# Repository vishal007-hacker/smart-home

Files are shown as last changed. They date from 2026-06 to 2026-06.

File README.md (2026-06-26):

# Smart Home 4-Channel AC Relay Controller

**WisRight Technologies Private Limited**

ESP32-based smart home controller for switching 4 independent 230V AC loads, with per-channel current and voltage sensing, manual override buttons, status LEDs, and an I²C LCD display.

The project is a complete KiCad 9 design — schematic, PCB layout, BOM, custom symbol/footprint for the HLK-PM01 AC-DC module, custom DRC rules for mains clearance, and Python generator scripts that build everything from a single `bom.csv`.

## Features

- **4 independent AC channels**, each with its own L/N/PE input terminal, fuse, relay, and L/N output terminal
- **Mains isolation** — HLK-PM01 isolated AC-DC module (230VAC → 5VDC, 600mA, 2.1 kV isolation)
- **Per-channel current sensing** — ACS712-05B Hall-effect IC (±5A, isolated)
- **Per-channel voltage sensing** — external ZMPT101B modules via I²C ADS1115 (16-bit, 4 channels)
- **Manual override** — 4 tactile buttons for local on/off control per channel
- **Status indication** — 4 green LEDs (one per channel) + 1 red power LED
- **I²C LCD support** — 4-pin header for an external 16×2 PCF8574 backpack LCD
- **UART programming header** — standard 6-pin pinout for any USB-to-serial adapter
- **Custom DRC rules** — 4mm HV-to-LV clearance, 3mm HV-to-HV, 2mm HV trace minimum, edge clearance
- **HV/LV isolation slot** — physical cut in the PCB between mains and logic sections

## Hardware overview

| Section | Parts |
|---|---|
| AC inputs | 4× Phoenix MKDS-1.5 3-pos terminals (L, N, PE per channel) |
| Protection | 4× T4A 5×20mm fuses (one per channel) + 1× S07K275 MOV across L1/N1 |
| Power supply | HLK-PM01 (230VAC → 5VDC) + AMS1117-3.3 (5V → 3.3V LDO) |
| Switching | 4× SANYOU SRD-05VDC SPDT relays (10A) driven by ULN2003A Darlington array |
| MCU | ESP32-WROOM-32E module (WiFi + Bluetooth) |
| AC outputs | 4× Phoenix MKDS-1.5 2-pos terminals (L_switched, N_passthrough per channel) |
| Current sense | 4× ACS712-05B (SOIC-8, ±5A range, internal isolation) |
| Voltage sense | 4× external ZMPT101B modules via 1× ADS1115 (I²C ADC at 0x48) |
| User interface | 4× 6mm tactile buttons + 4× green status LEDs + 1× red power LED + 4-pin I²C LCD header |
| Programming | 6-pin UART header (GND, +3V3, TXD0, RXD0, EN, IO0) |

Full bill of materials in [`bom.csv`](bom.csv) — 43 grouped rows, 76 component instances.

## Detailed components list

### Active devices

| Ref | Qty | Part | Package | Description |
|---|---|---|---|---|
| **U1** | 1 | ESP32-WROOM-32E | Module 18×25.5mm | Espressif WiFi+BT MCU, 240MHz dual-core, 4MB flash, integrated PCB antenna |
| **U2** | 1 | ULN2003A | DIP-16 | Texas Instruments 7-channel Darlington array (500mA per channel, up to 50V), drives relay coils |
| **U3** | 1 | AMS1117-3.3 | SOT-223-3 | Advanced Monolithic Systems 3.3V LDO regulator, 1A capacity, drops 5V→3.3V for ESP32 |
| **PS1** | 1 | HLK-PM01 | THT 34.2×20.2mm | Hi-Link AC-DC isolated SMPS module, 230VAC→5VDC @ 600mA, 2.1 kV isolation, 3W |
| **U4-U7** | 4 | ACS712ELCTR-05B | SOIC-8 | Allegro Hall-effect current sensor, ±5A range, 185 mV/A sensitivity, 2.1 kVrms isolation between IP± and signal pins |
| **U8** | 1 | ADS1115IDGSR | TSSOP-10 | Texas Instruments 16-bit Σ-Δ ADC, 4 single-ended channels, I²C interface, 860 SPS, PGA ±0.256V to ±6.144V (default address 0x48 with ADDR=GND) |
| **K1-K4** | 4 | SRD-05VDC-SL-C | THT | Sanyou SPDT relay, 5V coil ~70mA, contacts rated 10A @ 250VAC / 30VDC |

### Discrete components

| Ref | Qty | Value | Package | Use |
|---|---|---|---|---|
| **R1-R4** | 4 | 1 kΩ | 0805 SMD | Status LED current limit (D1-D4) |
| **R9** | 1 | 1 kΩ | 0805 SMD | Power LED current limit (D5) |
| **R5-R8** | 4 | 10 kΩ | 0805 SMD | Manual button pull-ups to +3V3 (SW1-SW4) |
| **R11** | 1 | 10 kΩ | 0805 SMD | ESP32 EN pin pull-up to +3V3 |
| **R12** | 1 | 10 kΩ | 0805 SMD | ESP32 BOOT (GPIO0) pull-up to +3V3 |
| **R13** | 1 | 4.7 kΩ | 0805 SMD | I²C SDA pull-up to +3V3 |
| **R14** | 1 | 4.7 kΩ | 0805 SMD | I²C SCL pull-up to +3V3 |
| **R15-R18** | 4 | 10 kΩ | 0805 SMD | ACS712 output divider (top) — scales 0-5V to 0-3.21V for ESP32 ADC |
| **R19-R22** | 4 | 18 kΩ | 0805 SMD | ACS712 output divider (bottom) |
| **C1** | 1 | 100 µF / 16V | Radial THT 6.3mm | HLK-PM01 +5V output bulk capacitor (absorbs ESP32 WiFi transient bursts) |
| **C2** | 1 | 10 µF | 0805 SMD | AMS1117 input cap |
| **C3** | 1 | 22 µF | 0805 SMD | AMS1117 output cap (recommended ≥22µF tantalum/ceramic for AMS1117 stability) |
| **C4** | 1 | 10 µF | 0805 SMD | ESP32 +3V3 bulk |
| **C5** | 1 | 100 nF | 0805 SMD | ESP32 3V3 decoupling (place within 3mm of module pin 2) |
| **C6** | 1 | 1 µF | 0805 SMD | EN pin RC delay (forms ~10ms power-up delay with R11=10k) |
| **C7** | 1 | 100 nF | 0805 SMD | ULN2003A VCC decoupling |
| **C8-C11** | 4 | 100 nF | 0805 SMD | ACS712 VCC decoupling (one per ACS712) |
| **C16** | 1 | 100 nF | 0805 SMD | ADS1115 VDD decoupling |
| **D1-D4** | 4 | LED 3mm green | THT | Per-channel relay status indicator |
| **D5** | 1 | LED 3mm red | THT | Power-on indicator (always on while +5V present) |
| **F1-F4** | 4 | T4A 5×20 mm | THT Schurter 0031.8201 holder | Slow-blow mains fuse, one per AC input channel |
| **RV1** | 1 | S07K275 | Disc D9mm | EPCOS metal oxide varistor, 275 VAC clamping, surge protection across L1/N1 |

### Switches

| Ref | Qty | Type | Use |
|---|---|---|---|
| **SW1-SW4** | 4 | 6mm tactile THT | Manual override buttons (one per channel) — momentary press toggles the relay |
| **SW5** | 1 | 6mm tactile THT | BOOT button — hold during reset to enter ESP32 download mode |
| **SW6** | 1 | 6mm tactile THT | RESET button — pulls ESP32 EN low |

### Connectors

| Ref | Qty | Type | Use |
|---|---|---|---|
| **J1A, J1B, J1C, J1D** | 4 | Phoenix MKDS-1.5 3-pos screw terminal, 5.08mm pitch | AC input per channel: L (Live), N (Neutral), PE (Protective Earth) |
| **J2A, J2B, J2C, J2D** | 4 | Phoenix MKDS-1.5 2-pos screw terminal, 5.08mm pitch | AC switched output per channel: L_out, N_passthrough |
| **J3** | 1 | 1×6 pin header, 2.54mm pitch | UART programming: GND, +3V3, TXD0, RXD0, EN, IO0 |
| **J4** | 1 | 1×4 pin header, 2.54mm pitch | External 16×2 LCD via PCF8574 I²C backpack: GND, +5V, SDA, SCL |
| **J5, J6, J7, J8** | 4 | 1×3 pin header, 2.54mm pitch | External ZMPT101B voltage sensor per channel: GND, +3V3, VOUT |

### External modules (not on PCB — user-supplied)

| Module | Quantity | Purpose | Connection |
|---|---|---|---|
| 16×2 LCD with PCF8574 I²C backpack | 1 | Display | 4-wire to J4 (I²C address typically 0x27 or 0x3F) |
| ZMPT101B AC voltage transformer module | 4 | Per-channel voltage measurement | AC side wires to J1A/B/C/D L+N; DC side 3-wire to J5/J6/J7/J8 |
| USB-to-Serial adapter (CP2102, CH340, FT232) | 1 | Firmware upload | 4–6 wire to J3 (only used during flashing) |

### Custom library parts (included in repo)

| Part | Files | Source |
|---|---|---|
| **HLK-PM01 symbol** | [`lib/hlk_pm01.kicad_sym`](lib/hlk_pm01.kicad_sym) | Custom — drawn from datasheet |
| **HLK-PM01 footprint** | [`hlk_pm01.pretty/HLK-PM01.kicad_mod`](hlk_pm01.pretty/HLK-PM01.kicad_mod) | Custom — drawn from datasheet (34.2 × 20.2 × 15 mm body, 4-pin THT) |

All other symbols and footprints are pulled from KiCad 9's standard libraries.

## Board

| | |
|---|---|
| Size | 200 × 100 mm, 2-layer FR4, 1.6 mm |
| Net classes | Default (0.25mm), Power (0.5mm), AC_HV (2.5mm, 4mm clearance, red) |
| HV/LV separation | Physical slot at x=110..118 mm with 4 mm minimum clearance enforced via custom DRU |
| Mounting | 4× 3.2 mm holes at corners |

## ESP32 GPIO map

| GPIO | Function | Notes |
|---|---|---|
| GPIO16-19 | Relay control K1-K4 | Drives ULN2003A inputs 1-4 |
| GPIO21, 22, 23, 25 | Manual buttons SW1-SW4 | Active-low, 10k pull-up to 3V3 |
| GPIO26, 27, 32, 33 | Status LEDs D1-D4 | Active-high, 1k current limit |
| GPIO13 | I²C SDA | Shared bus: LCD (0x27) + ADS1115 (0x48) |
| GPIO14 | I²C SCL | Same shared bus |
| GPIO34, 35, 36, 39 | Current sense A0-A3 | ADC1 input from ACS712 voltage dividers |
| GPIO0 | BOOT button | SW5 + 10k pull-up |
| EN | RESET button | SW6 + 10k pull-up + 1uF RC delay |
| TXD0 (GPIO1) | UART TX | Programming header J3 pin 3 |
| RXD0 (GPIO3) | UART RX | Programming header J3 pin 4 |

ADS1115 reads voltage sensors V_SENSE_1..4 on its 4 single-ended inputs.

## Repository layout

```
.
├── README.md                       # This file
├── bom.csv                         # Bill of materials (source of truth)
├── smart_home.kicad_pro            # KiCad project file
├── smart_home.kicad_sch            # Schematic
├── smart_home.kicad_pcb            # PCB layout (routed)
├── smart_home.kicad_dru            # Custom DRC rules (HV clearance)
├── fp-lib-table / sym-lib-table    # Registers the local hlk_pm01 lib
├── lib/
│   └── hlk_pm01.kicad_sym          # Custom symbol for HLK-PM01
├── hlk_pm01.pretty/
│   └── HLK-PM01.kicad_mod          # Custom footprint for HLK-PM01
├── generate_sch.py                 # Builds smart_home.kicad_sch from bom.csv
├── generate_pcb.py                 # Builds initial smart_home.kicad_pcb
├── add_acs712.py                   # Adds current-sense ICs to PCB (preserves traces)
├── add_voltage_sense.py            # Adds ADS1115 + voltage-sense headers
└── fabrication/                    # Gerbers + drill + pick-and-place (regenerable)
```

## Building the design

### Regenerate schematic
```
"C:\Program Files\KiCad\9.0\bin\python.exe" generate_sch.py
```

### Regenerate PCB (initial placement only — overwrites routing)
```
"C:\Program Files\KiCad\9.0\bin\python.exe" generate_pcb.py
"C:\Program Files\KiCad\9.0\bin\python.exe" add_acs712.py
"C:\Program Files\KiCad\9.0\bin\python.exe" add_voltage_sense.py
```

### Run DRC / ERC
```
"C:\Program Files\KiCad\9.0\bin\kicad-cli.exe" sch erc smart_home.kicad_sch --output erc.json
"C:\Program Files\KiCad\9.0\bin\kicad-cli.exe" pcb drc smart_home.kicad_pcb --format json --output drc.json
```

### Export fabrication files
```
"C:\Program Files\KiCad\9.0\bin\kicad-cli.exe" pcb export gerbers smart_home.kicad_pcb -o fabrication/ --no-protel-ext
"C:\Program Files\KiCad\9.0\bin\kicad-cli.exe" pcb export drill smart_home.kicad_pcb -o fabrication/ --format excellon --excellon-units mm --generate-map --map-format gerberx2
"C:\Program Files\KiCad\9.0\bin\kicad-cli.exe" pcb export pos smart_home.kicad_pcb -o fabrication/smart_home-pos.csv --format csv --units mm
```

Zip everything in `fabrication/` and upload to [JLCPCB](https://jlcpcb.com), [PCBWay](https://pcbway.com), or [OSHPark](https://oshpark.com).

## Flashing firmware

Wire a USB-to-serial adapter (CP2102, CH340, FT232) to **J3**:

| J3 pin | Adapter |
|---|---|
| 1 — GND | GND |
| 2 — +3V3 | leave disconnected (board self-powered from mains via PS1) |
| 3 — TXD0 | RX |
| 4 — RXD0 | TX |
| 5 — EN | DTR (optional, for auto-reset) |
| 6 — IO0 | RTS (optional, for auto-boot) |

**Safety:** Disconnect mains before plugging in the USB adapter. Then power the board from mains for upload — PS1 supplies 5V/3.3V and is galvanically isolated from mains.

**Manual reset sequence:** hold SW5 (BOOT) → press+release SW6 (RESET) → release SW5 → click Upload in your IDE.

Compatible with Arduino-ESP32, ESP-IDF, MicroPython, PlatformIO.

## External wiring per channel

Each ZMPT101B voltage sensor module is wired externally:

```
AC side (off-PCB):
    J1A pin 1 (L1) ──┐
                     ├── ZMPT101B "AC IN"
    J1A pin 2 (N1) ──┘

DC side (3-wire to PCB):
    ZMPT101B GND ── J5 pin 1
    ZMPT101B VCC ── J5 pin 2 (+3V3)
    ZMPT101B OUT ── J5 pin 3 (→ ADS1115 A0)
```

Repeat for channels 2, 3, 4 via J6, J7, J8 (→ ADS1115 A1, A2, A3).

Calibrate the trimmer pot on each ZMPT101B so its output stays in 0–3.3V range.

## Safety

- The HV side (input terminals, fuses, relays, MOV, PS1 AC input) carries lethal mains voltage. **Always disconnect mains before working on the board.**
- The HV/LV isolation slot in the PCB and the 4 mm HV-to-LV clearance rule provide creepage isolation per IEC 60664-1 for pollution degree 2, working voltage 250V.
- Each input has its own T4A slow-blow fuse (F1–F4). Replace only with the same rating.
- HLK-PM01 provides galvanic isolation between mains and the 5V rail (2.1 kV rated).
- ACS712-05B provides 2.1 kVrms isolation between the load current path and the MCU side.
- Use a properly rated enclosure with strain-relief for mains wiring. Do not power up outside an enclosure.

This is a hobby project. The author assumes no liability for damage, injury, or fire resulting from its use. Build and operate at your own risk and in compliance with local electrical codes.

## License

MIT License.

Copyright © 2026 **WisRight Technologies Private Limited**.

Permission is hereby granted, free of charge, to any person obtaining a copy of this hardware design and associated documentation files, to use, copy, modify, merge, publish, distribute, sublicense, and/or sell copies of the design, subject to the standard MIT terms — provided as-is, without warranty of any kind, especially regarding electrical safety. See [LICENSE](LICENSE) for the full text.

## Maintainer

Designed and maintained by **WisRight Technologies Private Limited**.

For commercial inquiries, custom variants (different relay ratings, board sizes, sensor configurations, or firmware integration), please open an issue on this repository.

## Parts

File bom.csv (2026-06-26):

Reference | Qty | Value | Description | KiCad Symbol | KiCad Footprint | Manufacturer Part No | Notes
U1 | 1 | ESP32-WROOM-32E | WiFi+BT MCU module 240MHz dual-core 4MB flash | RF_Module:ESP32-WROOM-32E | RF_Module:ESP32-WROOM-32 | ESP32-WROOM-32E-N4 | Espressif. Keep antenna keep-out area clear of copper. 4MB flash is sufficient.
U2 | 1 | ULN2003A | 7-channel Darlington driver array for relay coils | Driver_Motor:ULN2003A | Package_DIP:DIP-16_W7.62mm | ULN2003AN | Texas Instruments / STMicroelectronics. DIP-16 for hand soldering; switch to SOIC-16W if reflow assembly.
U3 | 1 | AMS1117-3.3 | 3.3V LDO linear regulator 1A | Regulator_Linear:AMS1117-3.3 | Package_TO_SOT_SMD:SOT-223-3_TabPin2 | AMS1117-3.3 | Advanced Monolithic Systems. Needs >=22uF output cap for stability. SOT-223 tab is GND.
PS1 | 1 | HLK-PM01 | Isolated AC-DC SMPS 230VAC to 5VDC 600mA 2.1kV iso | hlk_pm01:HLK-PM01 | hlk_pm01:HLK-PM01 | HLK-PM01 | Hi-Link. Custom KiCad symbol+footprint+3D model included in repo. 34.2x20.2x15mm THT.
K1-K4 | 4 | SRD-05VDC-SL-C | SPDT relay 10A@250VAC 5V coil ~70mA | Relay:SANYOU_SRD_Form_C | Relay_THT:Relay_SPDT_SANYOU_SRD_Series_Form_C | SRD-05VDC-SL-C | Sanyou. One per channel. ULN2003 sink current is ~70mA at 5V coil supply.
U4-U7 | 4 | ACS712-05B | Hall-effect AC current sensor +/-5A 185mV/A | Sensor_Current:ACS712xLCTR-05B | Package_SO:SOIC-8_3.9x4.9mm_P1.27mm | ACS712ELCTR-05B-T | Allegro Microsystems. One per channel. 2.1kVrms isolation IP+/- to signal pins. Load current MUST route through pins 1-4 (IP+) to pins 3-4 (IP-).
U8 | 1 | ADS1115 | 4-channel 16-bit I2C ADC PGA 860SPS | Analog_ADC:ADS1115IDGS | Package_SO:TSSOP-10_3x3mm_P0.5mm | ADS1115IDGSR | Texas Instruments. I2C address 0x48 with ADDR=GND. Reads voltage from 4x external ZMPT101B modules via J5-J8. Shares I2C bus with LCD.
D1-D4 | 4 | LED 3mm Green | Per-channel relay status indicator | Device:LED | LED_THT:LED_D3.0mm | LTL-4231N | Lite-On or any 3mm THT green LED. Vf ~2.2V at 5mA.
D5 | 1 | LED 3mm Red | Power-on indicator (always on with +5V) | Device:LED | LED_THT:LED_D3.0mm | LTL-4221N | Lite-On or any 3mm THT red LED. Vf ~2.0V at 5mA.
R1-R4 | 4 | 1k 0805 | Status LED current limit for D1-D4 | Device:R | Resistor_SMD:R_0805_2012Metric | RC0805FR-071KL | Yageo or any. Sets LED current ~3mA at 5V drive.
R9 | 1 | 1k 0805 | Power LED current limit for D5 | Device:R | Resistor_SMD:R_0805_2012Metric | RC0805FR-071KL | Same as R1-R4.
R5-R8 | 4 | 10k 0805 | Manual button pull-up to +3V3 for SW1-SW4 | Device:R | Resistor_SMD:R_0805_2012Metric | RC0805FR-0710KL | Yageo. Can be omitted if firmware enables ESP32 internal pull-ups.
R11 | 1 | 10k 0805 | ESP32 EN pin pull-up to +3V3 | Device:R | Resistor_SMD:R_0805_2012Metric | RC0805FR-0710KL | Required. Forms RC delay with C6 for clean power-up sequence.
R12 | 1 | 10k 0805 | ESP32 BOOT (GPIO0) pull-up to +3V3 | Device:R | Resistor_SMD:R_0805_2012Metric | RC0805FR-0710KL | Required. SW5 pulls IO0 low for download mode.
R13 | 1 | 4.7k 0805 | I2C SDA pull-up to +3V3 | Device:R | Resistor_SMD:R_0805_2012Metric | RC0805FR-074K7L | Required for I2C bus reliability with multiple devices (LCD + ADS1115).
R14 | 1 | 4.7k 0805 | I2C SCL pull-up to +3V3 | Device:R | Resistor_SMD:R_0805_2012Metric | RC0805FR-074K7L | Same as R13.
R15-R18 | 4 | 10k 0805 | ACS712 ADC divider top (Vout -> ADC node) | Device:R | Resistor_SMD:R_0805_2012Metric | RC0805FR-0710KL | One per ACS712. Divider ratio = 18/(10+18) = 0.643 scales 0-5V to 0-3.21V for ESP32 ADC.
R19-R22 | 4 | 18k 0805 | ACS712 ADC divider bottom (ADC node -> GND) | Device:R | Resistor_SMD:R_0805_2012Metric | RC0805FR-0718KL | One per ACS712. See R15-R18 note.
C1 | 1 | 100uF 16V | HLK-PM01 +5V output bulk capacitor | Device:C_Polarized | Capacitor_THT:CP_Radial_D6.3mm_P2.50mm | UVR1C101MED1TD | Nichicon or equivalent radial electrolytic. Absorbs ESP32 WiFi TX current bursts.
C2 | 1 | 10uF 0805 | AMS1117 input bulk capacitor | Device:C | Capacitor_SMD:C_0805_2012Metric | CL21A106KOQNNNE | Samsung X5R or X7R MLCC.
C3 | 1 | 22uF 0805 | AMS1117 output bulk capacitor | Device:C | Capacitor_SMD:C_0805_2012Metric | CL21A226MQQNNNE | Samsung X5R. AMS1117 requires >=22uF tantalum or ceramic for stability.
C4 | 1 | 10uF 0805 | ESP32 +3V3 bulk capacitor | Device:C | Capacitor_SMD:C_0805_2012Metric | CL21A106KOQNNNE | X5R MLCC.
C5 | 1 | 100nF 0805 | ESP32 +3V3 decoupling cap | Device:C | Capacitor_SMD:C_0805_2012Metric | CL21B104KBCNNNC | X7R MLCC. Place within 3mm of ESP32 module pin 2 (3V3).
C6 | 1 | 1uF 0805 | EN pin RC delay capacitor | Device:C | Capacitor_SMD:C_0805_2012Metric | CL21B105KAFNNNE | X7R MLCC. With R11=10k forms 10ms RC delay on power-up.
C7 | 1 | 100nF 0805 | ULN2003A VCC decoupling cap | Device:C | Capacitor_SMD:C_0805_2012Metric | CL21B104KBCNNNC | X7R MLCC.
C8-C11 | 4 | 100nF 0805 | ACS712 VCC decoupling cap (one per IC) | Device:C | Capacitor_SMD:C_0805_2012Metric | CL21B104KBCNNNC | X7R MLCC. Place within 3mm of ACS712 pin 8.
C16 | 1 | 100nF 0805 | ADS1115 VDD decoupling cap | Device:C | Capacitor_SMD:C_0805_2012Metric | CL21B104KBCNNNC | X7R MLCC.
F1-F4 | 4 | T4A 5x20mm | Slow-blow mains fuse (one per channel) | Device:Fuse | Fuse:Fuseholder_Cylinder-5x20mm_Schurter_0031_8201_Horizontal_Open | 0034.3122 | Schurter 0034.3122 (T4AH 250V) + 0031.8201 holder. Rated 4A; matches relay 10A spec with safety margin.
RV1 | 1 | S07K275 | Metal oxide varistor 275VAC clamping (L1/N1) | Device:Varistor | Varistor:RV_Disc_D9mm_W5.2mm_P5mm | S07K275 | EPCOS / TDK. Surge protection across input 1 only (where logic supply taps). 270V continuous max.
SW1-SW4 | 4 | 6mm tactile THT | Manual override buttons (one per channel) | Switch:SW_Push | Button_Switch_THT:SW_PUSH_6mm | TS-1102-G | Any 6mm tactile through-hole switch. Momentary action.
SW5 | 1 | 6mm tactile THT | BOOT button - hold during reset for download mode | Switch:SW_Push | Button_Switch_THT:SW_PUSH_6mm | TS-1102-G | Same as SW1-SW4. Pulls GPIO0 to GND.
SW6 | 1 | 6mm tactile THT | RESET button - pulls EN low | Switch:SW_Push | Button_Switch_THT:SW_PUSH_6mm | TS-1102-G | Same as SW1-SW4. Pulls EN to GND.
J1A | 1 | Screw terminal 3-pos | AC input ch1 - L1/N1/PE | Connector_Generic:Conn_01x03 | TerminalBlock_Phoenix:TerminalBlock_Phoenix_MKDS-1,5-3-5.08_1x03_P5.08mm_Horizontal | 1715022 | Phoenix Contact MKDS-1.5/3-5.08. Rated 16A 400VAC. Use 1.5mm^2 wire.
J1B | 1 | Screw terminal 3-pos | AC input ch2 - L2/N2/PE | Connector_Generic:Conn_01x03 | TerminalBlock_Phoenix:TerminalBlock_Phoenix_MKDS-1,5-3-5.08_1x03_P5.08mm_Horizontal | 1715022 | Same as J1A.
J1C | 1 | Screw terminal 3-pos | AC input ch3 - L3/N3/PE | Connector_Generic:Conn_01x03 | TerminalBlock_Phoenix:TerminalBlock_Phoenix_MKDS-1,5-3-5.08_1x03_P5.08mm_Horizontal | 1715022 | Same as J1A.
J1D | 1 | Screw terminal 3-pos | AC input ch4 - L4/N4/PE | Connector_Generic:Conn_01x03 | TerminalBlock_Phoenix:TerminalBlock_Phoenix_MKDS-1,5-3-5.08_1x03_P5.08mm_Horizontal | 1715022 | Same as J1A.
J2A | 1 | Screw terminal 2-pos | Load output ch1 - L1_OUT/N1 | Connector_Generic:Conn_01x02 | TerminalBlock_Phoenix:TerminalBlock_Phoenix_MKDS-1,5-2-5.08_1x02_P5.08mm_Horizontal | 1715019 | Phoenix Contact MKDS-1.5/2-5.08. Rated 16A 400VAC.
J2B | 1 | Screw terminal 2-pos | Load output ch2 - L2_OUT/N2 | Connector_Generic:Conn_01x02 | TerminalBlock_Phoenix:TerminalBlock_Phoenix_MKDS-1,5-2-5.08_1x02_P5.08mm_Horizontal | 1715019 | Same as J2A.
J2C | 1 | Screw terminal 2-pos | Load output ch3 - L3_OUT/N3 | Connector_Generic:Conn_01x02 | TerminalBlock_Phoenix:TerminalBlock_Phoenix_MKDS-1,5-2-5.08_1x02_P5.08mm_Horizontal | 1715019 | Same as J2A.
J2D | 1 | Screw terminal 2-pos | Load output ch4 - L4_OUT/N4 | Connector_Generic:Conn_01x02 | TerminalBlock_Phoenix:TerminalBlock_Phoenix_MKDS-1,5-2-5.08_1x02_P5.08mm_Horizontal | 1715019 | Same as J2A.
J3 | 1 | Pin header 1x06 2.54mm | UART programming header | Connector_Generic:Conn_01x06 | Connector_PinHeader_2.54mm:PinHeader_1x06_P2.54mm_Vertical | M20-9990645 | Harwin or any 6-pin 0.1in vertical header. Pinout: GND / +3V3 / TXD0 / RXD0 / EN / IO0.
J4 | 1 | Pin header 1x04 2.54mm | External 16x2 LCD I2C connector | Connector_Generic:Conn_01x04 | Connector_PinHeader_2.54mm:PinHeader_1x04_P2.54mm_Vertical | M20-9990445 | 4-pin 0.1in vertical header. Pinout: GND / +5V / SDA / SCL. Connects to a PCF8574-backpack LCD (I2C 0x27 or 0x3F).
J5-J8 | 4 | Pin header 1x03 2.54mm | External ZMPT101B voltage sensor connection | Connector_Generic:Conn_01x03 | Connector_PinHeader_2.54mm:PinHeader_1x03_P2.54mm_Vertical | M20-9990345 | 3-pin 0.1in vertical header. Pinout: GND / +3V3 / VOUT. One per channel. Wire to external ZMPT101B module's DC pins.
#EXTERNAL |  |  | Modules NOT on the PCB - buy these separately |  |  |  | User-supplied. Wire to the headers above.
LCD1 | 1 | 16x2 LCD with PCF8574 I2C backpack | 16-char x 2-line HD44780 LCD + PCF8574 I2C expander |  | External module | 1602A + PCF8574T | Generic. Default I2C address 0x27 (some 0x3F). Connect 4 wires to J4: GND/+5V/SDA/SCL.
VS1-VS4 | 4 | ZMPT101B | AC voltage transformer sensor module 0-250VAC |  | External module | ZMPT101B | Generic module with on-board op-amp + trimmer pot. AC side: wire to J1A-D L/N. DC side: 3 wires to J5-J8 (GND/+3V3/OUT). Calibrate trimmer so output stays in 0-3.3V range.
USB1 | 1 | USB-to-Serial adapter | 3.3V TTL UART adapter for ESP32 flashing |  | External tool | CP2102 or CH340 or FT232 | Only needed during firmware upload. Connect to J3. DO NOT power J3.+3V3 pin from adapter - board self-powers from mains via PS1.

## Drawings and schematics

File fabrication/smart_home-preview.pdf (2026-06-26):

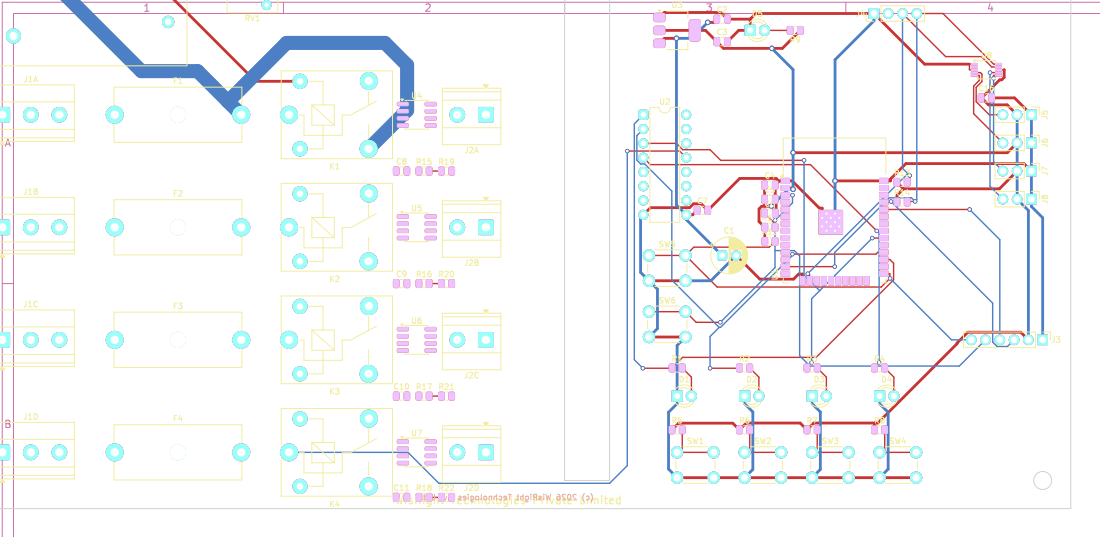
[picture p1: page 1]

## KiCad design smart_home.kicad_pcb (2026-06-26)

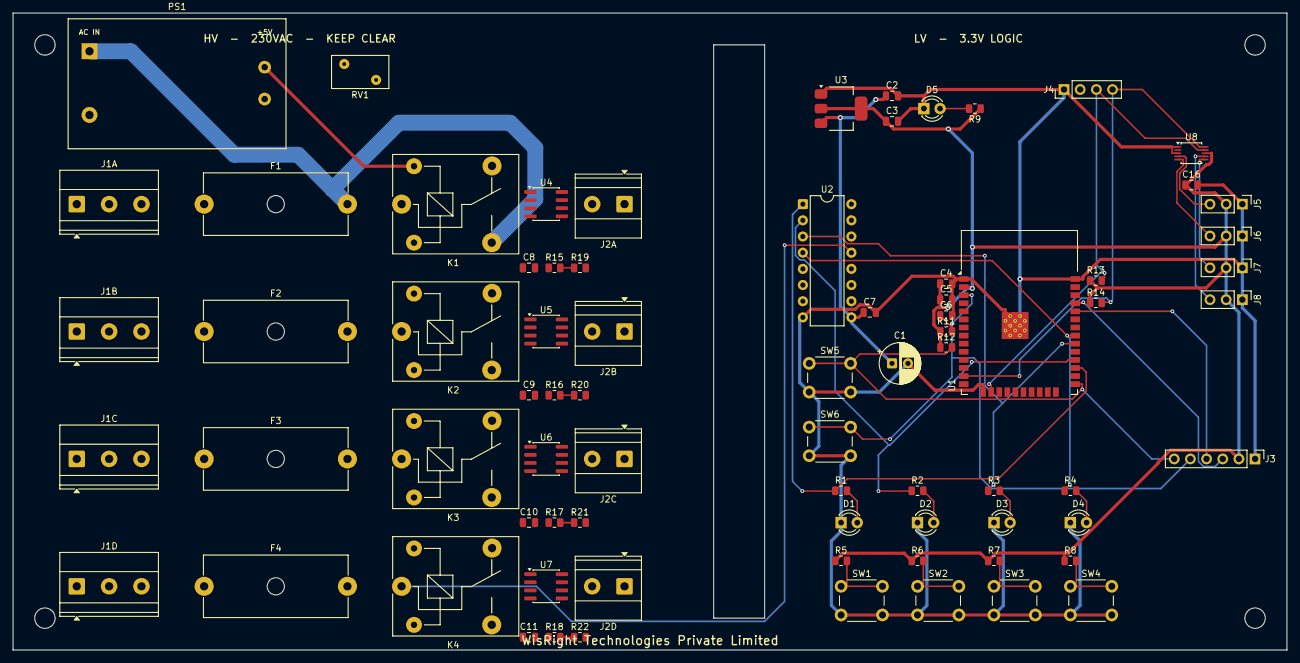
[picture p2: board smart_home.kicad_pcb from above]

Board: 2 copper layers, 200.0 x 100.0 mm, 76 parts (0 on the bottom side), 59 nets.

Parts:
C1: 100uF/16V; CP_Radial_D6.3mm_P2.50mm
C2, C4: 10uF; C_0805_2012Metric
C3: 22uF; C_0805_2012Metric
C5, C7, C8, C9, C10, C11, C16: 100nF; C_0805_2012Metric
C6: 1uF; C_0805_2012Metric
D1, D2, D3, D4: LED_Green; LED_D3.0mm
D5: LED_Red; LED_D3.0mm
F1, F2, F3, F4: T4A; Fuseholder_Cylinder-5x20mm_Schurter_0031_8201_Horizontal_Op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
J1A: AC_IN_1; TerminalBlock_Phoenix_MKDS-1,5-3-5.08_1x03_P5.08mm_Horizont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
J1B: AC_IN_2; TerminalBlock_Phoenix_MKDS-1,5-3-5.08_1x03_P5.08mm_Horizont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
J1C: AC_IN_3; TerminalBlock_Phoenix_MKDS-1,5-3-5.08_1x03_P5.08mm_Horizont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
J1D: AC_IN_4; TerminalBlock_Phoenix_MKDS-1,5-3-5.08_1x03_P5.08mm_Horizont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
J2A: LOAD_1; TerminalBlock_Phoenix_MKDS-1,5-2-5.08_1x02_P5.08mm_Horizont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
J2B: LOAD_2; TerminalBlock_Phoenix_MKDS-1,5-2-5.08_1x02_P5.08mm_Horizont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
J2C: LOAD_3; TerminalBlock_Phoenix_MKDS-1,5-2-5.08_1x02_P5.08mm_Horizont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
J2D: LOAD_4; TerminalBlock_Phoenix_MKDS-1,5-2-5.08_1x02_P5.08mm_Horizont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
J3: PROG; PinHeader_1x06_P2.54mm_Vertical
J4: LCD I2C; PinHeader_1x04_P2.54mm_Vertical
J5: V_SENSE_1; PinHeader_1x03_P2.54mm_Vertical
J6: V_SENSE_2; PinHeader_1x03_P2.54mm_Vertical
J7: V_SENSE_3; PinHeader_1x03_P2.54mm_Vertical
J8: V_SENSE_4; PinHeader_1x03_P2.54mm_Vertical
K1, K2, K3, K4: SRD-05VDC-SL-C; Relay_SPDT_SANYOU_SRD_Series_Form_C
PS1: HLK-PM01
R1, R2, R3, R4, R9: 1k; R_0805_2012Metric
R5, R6, R7, R8, R11, R12, R15, R16, R17, R18: 10k; R_0805_2012Metric
R13, R14: 4.7k; R_0805_2012Metric
R19, R20, R21, R22: 18k; R_0805_2012Metric
RV1: S07K275; RV_Disc_D9mm_W5.2mm_P5mm
SW1, SW2, SW3, SW4, SW5, SW6: TACT_6mm; SW_PUSH_6mm
U1: ESP32-WROOM-32E; ESP32-WROOM-32
U2: ULN2003A; DIP-16_W7.62mm
U3: AMS1117-3.3; SOT-223-3_TabPin2
U4, U5, U6, U7: ACS712-05B; SOIC-8_3.9x4.9mm_P1.27mm
U8: ADS1115; TSSOP-10_3x3mm_P0.5mm

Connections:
+3V3: C3.1, C4.1, C5.1, C16.1, J3.2, J5.2, J6.2, J7.2, J8.2, R5.1, R6.1, R7.1, R8.1, R9.1, R11.1, R12.1, R13.1, R14.1, U1.2, U3.2, U8.8
+5V: C1.1, C2.1, C7.1, C8.1, C9.1, C10.1, C11.1, J4.2, K1.5, K2.5, K3.5, K4.5, PS1.3, U2.9, U3.3, U4.8, U5.8, U6.8, U7.8
BTN1: R5.2, SW1.1
BTN2: R6.2, SW2.1
BTN3: R7.2, SW3.1
BTN4: R8.2, SW4.1
COIL1: K1.1, U2.16
COIL2: K2.1, U2.15
COIL3: K3.1, U2.14
COIL4: K4.1, U2.13
EN: C6.1, J3.5, R11.2, SW6.1, U1.3
GND: C1.2, C2.2, C3.2, C4.2, C5.2, C6.2, C7.2, C8.2, C9.2, C10.2, C11.2, C16.2, D1.1, D2.1, D3.1, D4.1, D5.1, J3.1, J4.1, J5.1, J6.1, J7.1, J8.1, PS1.4, R19.2, R20.2, R21.2, R22.2, SW1.2, SW2.2, SW3.2, SW4.2, SW5.2, SW6.2, U1.1, U1.15, U1.38, U1.39, U2.8, U3.1, U4.5, U5.5, U6.5, U7.5, U8.1, U8.3
IO0: J3.6, R12.2, SW5.1, U1.25
IO16: R1.1, U1.27, U2.1
IO17: R2.1, U1.28, U2.2
IO18: R3.1, U1.30, U2.3
IO19: R4.1, U1.31, U2.4
I_SENSE_1: R15.2, R19.1
I_SENSE_2: R16.2, R20.1
I_SENSE_3: R17.2, R21.1
I_SENSE_4: R18.2, R22.1
L1: F1.2, K1.3, PS1.1, RV1.1
L1_RAW: F1.1, J1A.1
L2: F2.2, K2.3
L2_RAW: F2.1, J1B.1
L3: F3.2, K3.3
L3_RAW: F3.1, J1C.1
L4: F4.2, K4.3
L4_RAW: F4.1, J1D.1
LED1: D1.2, R1.2
LED2: D2.2, R2.2
LED3: D3.2, R3.2
LED4: D4.2, R4.2
LED_PWR: D5.2, R9.2
LOAD1: K1.2, U4.1, U4.2
LOAD1_OUT: J2A.1, U4.3, U4.4
LOAD2: K2.2, U5.1, U5.2
LOAD2_OUT: J2B.1, U5.3, U5.4
LOAD3: K3.2, U6.1, U6.2
LOAD3_OUT: J2C.1, U6.3, U6.4
LOAD4: K4.2, U7.1, U7.2
LOAD4_OUT: J2D.1, U7.3, U7.4
N1: J1A.2, J2A.2, PS1.2, RV1.2
N2: J1B.2, J2B.2
N3: J1C.2, J2C.2
N4: J1D.2, J2D.2
PE: J1A.3, J1B.3, J1C.3, J1D.3
RXD0: J3.4, U1.34
SCL_LCD: J4.4, R14.2, U1.13, U8.10
SDA_LCD: J4.3, R13.2, U1.16, U8.9
TXD0: J3.3, U1.35
VOUT_1: R15.1, U4.7
VOUT_2: R16.1, U5.7
VOUT_3: R17.1, U6.7
VOUT_4: R18.1, U7.7
V_SENSE_1: J5.3, U8.4
V_SENSE_2: J6.3, U8.5
V_SENSE_3: J7.3, U8.6
V_SENSE_4: J8.3, U8.7

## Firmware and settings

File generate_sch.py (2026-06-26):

"""
Generate a complete smart_home.kicad_sch for the 4-channel ESP32 smart home
AC relay PCB project.

Reads bom.csv (27 components), extracts each referenced library symbol from
the standard KiCad 9 symbol libraries (plus the local hlk_pm01 lib and the
power lib for GND/+5V/+3V3 power flags), places component instances on an
A3 sheet in a sensible HV-left / LV-right grid layout, and adds wires plus
labels for the major nets described in the spec.

Re-run this script whenever bom.csv changes; it overwrites smart_home.kicad_sch.
"""

import csv
import os
import re
import uuid
from pathlib import Path

# --------------------------------------------------------------------------
# Paths
# --------------------------------------------------------------------------
PROJECT_DIR   = Path(__file__).resolve().parent
BOM_PATH      = PROJECT_DIR / "bom.csv"
SCH_PATH      = PROJECT_DIR / "smart_home.kicad_sch"
HLK_LIB_PATH  = PROJECT_DIR / "lib" / "hlk_pm01.kicad_sym"
KICAD_SYMS    = Path(r"C:\Program Files\KiCad\9.0\share\kicad\symbols")


# --------------------------------------------------------------------------
# UUID helper — every primitive needs one
# --------------------------------------------------------------------------
def U() -> str:
    return str(uuid.uuid4())


ROOT_UUID = "a1b2c3d4-0000-0000-0000-000000000001"  # match existing file


# --------------------------------------------------------------------------
# BOM parsing — the CSV has *unquoted* commas in two TerminalBlock footprint
# names (J1, J2). The header is 8 columns; any row with >8 columns means a
# comma leaked into the Footprint or Manufacturer Part No field. Detect and
# rejoin so columns realign.
# --------------------------------------------------------------------------
def load_bom():
    rows = list(csv.reader(open(BOM_PATH, encoding="utf-8")))
    header = rows[0]
    out = []
    for r in rows[1:]:
        if not r or not r[0].strip():
            continue
        # Skip comment rows (Reference starts with '#')
        if r[0].lstrip().startswith("#"):
            continue
        if len(r) > len(header):
            # The footprint field (idx 5) contains a comma. Glue idx 5 + 6 back.
            excess = len(r) - len(header)
            fp = ",".join(r[5 : 5 + 1 + excess])
            r = r[:5] + [fp] + r[5 + 1 + excess :]
        row = dict(zip(header, r))
        # Skip external modules — they have no KiCad symbol (not placed on PCB)
        if not row.get("KiCad Symbol", "").strip():
            continue
        out.append(row)
    return out


# --------------------------------------------------------------------------
# Expand grouped references like "K1-K4" or "D1-D4" into individual rows.
# Returns a flat list of (ref, value, lib_id, footprint, description) tuples.
# --------------------------------------------------------------------------
def expand_components(bom):
    parts = []
    for row in bom:
        ref_raw = row["Reference"].strip()
        value   = row["Value"].strip()
        lib_id  = row["KiCad Symbol"].strip()
        fp      = row["KiCad Footprint"].strip()
        desc    = row["Description"].strip()

        m = re.match(r"^([A-Za-z]+)(\d+)-([A-Za-z]+)?(\d+)$", ref_raw)
        if m:
            prefix, start, _, end = m.groups()
            for n in range(int(start), int(end) + 1):
                parts.append((f"{prefix}{n}", value, lib_id, fp, desc))
        else:
            parts.append((ref_raw, value, lib_id, fp, desc))
    return parts


# --------------------------------------------------------------------------
# Extract a top-level (symbol "NAME" ...) block from a .kicad_sym library.
# Uses balanced-paren scanning (string-aware).
# --------------------------------------------------------------------------
def extract_symbol(lib_path: Path, sym_name: str) -> str:
    text = lib_path.read_text(encoding="utf-8")
    needle = f'(symbol "{sym_name}"'
    i = text.find(needle)
    if i < 0:
        raise RuntimeError(f"Symbol {sym_name!r} not found in {lib_path}")

    depth = 0
    in_str = False
    esc = False
    j = i
    while j < len(text):
        c = text[j]
        if esc:
            esc = False
        elif c == "\\":
            esc = True
        elif c == '"':
            in_str = not in_str
        elif not in_str:
            if c == "(":
                depth += 1
            elif c == ")":
                depth -= 1
                if depth == 0:
                    return text[i : j + 1]
        j += 1
    raise RuntimeError(f"Unterminated symbol block for {sym_name}")


# Some lib_ids in the BOM don't resolve in the stock KiCad 9 libraries (e.g.
# ULN2003A actually lives in Transistor_Array, not Driver_Motor). Remap here
# without modifying bom.csv. The lib_id stored in the *placed component* is
# still the rewritten one, which keeps lib_symbols consistent.
LIB_ID_REMAP = {
    "Driver_Motor:ULN2003A": "Transistor_Array:ULN2003A",
}


# Map lib_id -> (library file path, symbol name)
def lib_id_to_path(lib_id: str) -> tuple[Path, str]:
    lib, sym = lib_id.split(":", 1)
    if lib == "hlk_pm01":
        return HLK_LIB_PATH, sym
    return KICAD_SYMS / f"{lib}.kicad_sym", sym


def resolve_lib_id(lib_id: str) -> str:
    return LIB_ID_REMAP.get(lib_id, lib_id)


# Rewrite an extracted symbol so its top-level name is prefixed with "lib:" —
# that's what KiCad puts in lib_symbols of a .kicad_sch (e.g. "Device:R", not
# just "R"). Sub-unit symbols inside keep their original names.
def rename_top_symbol(block: str, lib_id: str) -> str:
    # Only replace the very first '(symbol "NAME"' occurrence.
    return re.sub(
        r'^\(symbol\s+"[^"]+"',
        f'(symbol "{lib_id}"',
        block,
        count=1,
    )


# --------------------------------------------------------------------------
# Split a symbol block into its child fragments (top-level S-exps inside the
# outer (symbol ...) parens). Used to flatten `(extends ...)` symbols.
# --------------------------------------------------------------------------
def split_symbol_children(block: str) -> tuple[str, list[str]]:
    """Return (header_line, [child_sexpr_strings]).

    header_line is the '(symbol "NAME"' opener. children are the inner forms
    in order (each a complete balanced S-exp like '(extends "X")' or
    '(property "Reference" "U" (at ...))' or '(symbol "X_0_1" ...)').
    """
    # Find the opener
    m = re.match(r'^\(symbol\s+"[^"]+"\s*', block)
    assert m, f"bad symbol header: {block[:80]!r}"
    header = m.group(0).rstrip()
    body = block[m.end() : -1]  # strip trailing ')'

    children = []
    i = 0
    while i < len(body):
        # Skip whitespace
        while i < len(body) and body[i] in " \t\r\n":
            i += 1
        if i >= len(body):
            break
        if body[i] != "(":
            # Stray text — shouldn't happen
            i += 1
            continue
        # Walk balanced parens
        depth = 0
        in_str = False
        esc = False
        start = i
        while i < len(body):
            c = body[i]
            if esc:
                esc = False
            elif c == "\\":
                esc = True
            elif c == '"':
                in_str = not in_str
            elif not in_str:
                if c == "(":
                    depth += 1
                elif c == ")":
                    depth -= 1
                    if depth == 0:
                        i += 1
                        children.append(body[start:i])
                        break
            i += 1
    return header, children


def child_head(sexpr: str) -> str:
    """Return the first token of an S-exp, e.g. 'extends' or 'property'."""
    m = re.match(r'^\(\s*([A-Za-z_][A-Za-z0-9_]*)', sexpr)
    return m.group(1) if m else ""


def child_property_name(sexpr: str) -> str | None:
    m = re.match(r'^\(\s*property\s+"([^"]+)"', sexpr)
    return m.group(1) if m else None


def _child_symbol_name(sexpr: str) -> str | None:
    """If sexpr is (symbol "NAME" ...), return NAME, else None."""
    m = re.match(r'^\(\s*symbol\s+"([^"]+)"', sexpr)
    return m.group(1) if m else None


def flatten_extends(block: str, parent_block: str, child_name: str) -> str:
    """Replace (extends "P") in a child symbol with the parent's pins,
    graphics and sub-unit symbols. The child keeps its own properties
    (overriding any same-named parent property). Sub-symbol names inherited
    from the parent are rewritten to use the child's name (so they match
    the conventional `<name>_<unit>_<bodystyle>` form KiCad expects)."""
    child_hdr, child_children = split_symbol_children(block)
    _,         parent_children = split_symbol_children(parent_block)

    parent_name_match = re.match(r'^\(symbol\s+"([^"]+)"', parent_block)
    parent_name = parent_name_match.group(1) if parent_name_match else None

    # Drop the (extends ...) from the child.
    child_children = [c for c in child_children if child_head(c) != "extends"]

    # Collect property names defined by the child so we don't duplicate them
    # when pulling from the parent.
    child_prop_names = {
        child_property_name(c) for c in child_children
        if child_head(c) == "property"
    }

    # From the parent, take everything EXCEPT (extends), and skip any
    # property whose name is already overridden by the child. Keep the
    # parent's pin_numbers/pin_names settings and sub-symbols (which carry
    # the actual graphics + pins). Rename sub-symbols from
    # "<parent>_<u>_<b>" to "<child>_<u>_<b>".
    merged_parent = []
    for c in parent_children:
        h = child_head(c)
        if h == "extends":
            continue
        if h == "property":
            name = child_property_name(c)
            if name in child_prop_names:
                continue
        if h == "symbol" and parent_name:
            sub_name = _child_symbol_name(c)
            if sub_name and sub_name.startswith(parent_name + "_"):
                suffix = sub_name[len(parent_name):]
                new_sub = child_name + suffix
                c = re.sub(
                    r'^\(\s*symbol\s+"[^"]+"',
                    f'(symbol "{new_sub}"',
                    c,
                    count=1,
                )
        merged_parent.append(c)

    # Put child properties first (matches KiCad's output ordering), then
    # everything inherited from the parent.
    new_children = child_children + merged_parent

    body = "\n\t\t".join(new_children)
    return f"{child_hdr}\n\t\t{body}\n\t)"


# --------------------------------------------------------------------------
# Layout — A3 sheet (420 x 297 mm). HV components on the left half, LV on the
# right. Each entry: (ref, x_mm, y_mm, rotation_deg).
#
# NEW DESIGN: 4 fully-isolated AC inputs. Each input row has:
#   J1x (3-pos input terminal)  ->  Fx (fuse)  ->  Kx.COM (relay COM)
#                                                  Kx.NO -> J2x (2-pos load out)
# Input 1 (top row) also hosts RV1 (across L1/N1) and PS1 (HLK-PM01 PSU).
# --------------------------------------------------------------------------
LAYOUT = {
    # ---- HV side (left) — 4 input rows -----------------------------------
    # Row 1 (top) — input 1 with PSU + MOV
    "J1A": ( 30,  60, 0),    # AC input 1
    "F1":  ( 60,  60, 0),    # fuse 1
    "K1":  ( 95,  60, 0),    # relay 1
    "J2A": (135,  60, 0),    # load output 1

    "RV1": ( 60,  80, 0),    # varistor across L1-N1
    "PS1": (100,  80, 0),    # HLK-PM01 from L1/N1

    # Row 2 — input 2
    "J1B": ( 30, 115, 0),
    "F2":  ( 60, 115, 0),
    "K2":  ( 95, 115, 0),
    "J2B": (135, 115, 0),

    # Row 3 — input 3
    "J1C": ( 30, 160, 0),
    "F3":  ( 60, 160, 0),
    "K3":  ( 95, 160, 0),
    "J2C": (135, 160, 0),

    # Row 4 — input 4
    "J1D": ( 30, 205, 0),
    "F4":  ( 60, 205, 0),
    "K4":  ( 95, 205, 0),
    "J2D": (135, 205, 0),

    # ---- LV side (right) — shifted right to clear HV layout -------------
    "C1":  (175,  95, 0),    # HLK bulk cap

    # AMS1117 regulator
    "U3":  (195,  70, 0),
    "C2":  (180,  75, 0),
    "C3":  (210,  75, 0),

    # ESP32 module
    "U1":  (295, 120, 0),

    # ESP32 support
    "C4":  (265,  95, 0),
    "C5":  (280,  95, 0),
    "C6":  (265, 150, 0),
    "R11": (270, 135, 0),    # EN pullup
    "R12": (325, 135, 0),    # IO0 pullup

    # ULN2003 + decoupling
    "U2":  (210, 155, 0),
    "C7":  (190, 140, 0),

    # Manual override buttons + pullups
    "SW1": (345, 165, 0),
    "SW2": (345, 180, 0),
    "SW3": (345, 195, 0),
    "SW4": (345, 210, 0),
    "R5":  (360, 160, 0),
    "R6":  (360, 175, 0),
    "R7":  (360, 190, 0),
    "R8":  (360, 205, 0),

    # BOOT / RESET buttons
    "SW5": (330, 225, 0),    # BOOT
    "SW6": (315, 225, 0),    # RESET

    # Status LEDs + series resistors
    "D1":  (245, 225, 0),
    "D2":  (245, 240, 0),
    "D3":  (245, 255, 0),
    "D4":  (245, 270, 0),
    "R1":  (230, 225, 0),
    "R2":  (230, 240, 0),
    "R3":  (230, 255, 0),
    "R4":  (230, 270, 0),

    # Power indicator
    "D5":  (205, 100, 0),
    "R9":  (190, 100, 0),

    # Programming header
    "J3":  (395, 100, 0),

    # LCD I2C header + pull-ups (top-right area, near ESP32 module)
    # External 16x2 LCD with PCF8574 backpack: GND, +5V, SDA, SCL
    "J4":  (395,  60, 0),    # 4-pin header for external LCD
    "R13": (370,  50, 0),    # SDA pull-up to +3V3
    "R14": (370,  60, 0),    # SCL pull-up to +3V3

    # ---- Per-channel AC current sensing (ACS712-05B + decoupling + divider) ----
    # One ACS712 per channel between Kx.NO and J2x.1, with +5V decoupling
    # cap (C8-C11) and a 10k/18k divider (R15-R18 / R19-R22) on VIOUT for the
    # ESP32 ADC.
    # ACS712 placed to the right of each channel row's relay/J2 cluster; the
    # divider passives sit just below the IC. The +5V decoupling cap sits
    # immediately next to VCC (pin 8).
    "U4":  (160,  60, 0),    # ch1 ACS712
    "C8":  (155,  68, 0),    # ch1 decoupling 100nF
    "R15": (172,  64, 0),    # ch1 divider top 10k (Vout -> ADC)
    "R19": (172,  72, 0),    # ch1 divider bot 18k (ADC -> GND)

    "U5":  (160, 115, 0),    # ch2 ACS712
    "C9":  (155, 123, 0),
    "R16": (172, 119, 0),
    "R20": (172, 127, 0),

    "U6":  (160, 160, 0),    # ch3 ACS712
    "C10": (155, 168, 0),
    "R17": (172, 164, 0),
    "R21": (172, 172, 0),

    "U7":  (160, 205, 0),    # ch4 ACS712
    "C11": (155, 213, 0),
    "R18": (172, 209, 0),
    "R22": (172, 217, 0),

    # ---- Per-channel AC voltage sensing (ADS1115 + external ZMPT101B) -----
    # ADS1115 I2C 16-bit 4-channel ADC samples ZMPT101B AC voltage sensor
    # outputs (one per channel). The ZMPT101B modules are EXTERNAL; J5-J8
    # are 3-pin headers (GND, +3V3, VOUT) that connect to each module.
    # ADS1115 must run at 3.3V because the ESP32 GPIO is not 5V-tolerant and
    # the I2C bus is shared with the LCD on the 3V3 rail; running the ADC
    # at 5V would back-drive 5V on the I2C lines and damage the ESP32.
    # ZMPT101B output is centered at VCC/2 = 1.65V at 3.3V supply, which
    # keeps the AC signal within the 0-3.3V ADS1115 input range.
    # Placed in the LV upper-right area, near the LCD I2C connector (J4) and
    # well clear of the ESP32 module (U1 at 295,120).
    "U8":  (245,  60, 0),    # ADS1115 TSSOP-10
    "C16": (230,  60, 0),    # 100nF VDD decoupling, near U8
    "J5":  (395, 130, 0),    # ch1 external ZMPT101B header (GND/+3V3/VOUT)
    "J6":  (395, 150, 0),    # ch2
    "J7":  (395, 170, 0),    # ch3
    "J8":  (395, 190, 0),    # ch4
}


# --------------------------------------------------------------------------
# Component instance emitter
# --------------------------------------------------------------------------
def emit_symbol(ref, value, lib_id, footprint, x, y, rot, root_uuid):
    sym_uuid = U()
    return f'''\t(symbol
\t\t(lib_id "{lib_id}")
\t\t(at {x} {y} {rot})
\t\t(unit 1)
\t\t(exclude_from_sim no)
\t\t(in_bom yes)
\t\t(on_board yes)
\t\t(dnp no)
\t\t(uuid "{sym_uuid}")
\t\t(property "Reference" "{ref}"
\t\t\t(at {x + 2.54} {y - 5.08} 0)
\t\t\t(effects (font (size 1.27 1.27)) (justify left))
\t\t)
\t\t(property "Value" "{value}"
\t\t\t(at {x + 2.54} {y + 5.08} 0)
\t\t\t(effects (font (size 1.27 1.27)) (justify left))
\t\t)
\t\t(property "Footprint" "{footprint}"
\t\t\t(at {x} {y} 0)
\t\t\t(effects (font (size 1.27 1.27)) hide)
\t\t)
\t\t(property "Datasheet" ""
\t\t\t(at {x} {y} 0)
\t\t\t(effects (font (size 1.27 1.27)) hide)
\t\t)
\t\t(property "Description" ""
\t\t\t(at {x} {y} 0)
\t\t\t(effects (font (size 1.27 1.27)) hide)
\t\t)
\t\t(instances
\t\t\t(project "smart_home"
\t\t\t\t(path "/{root_uuid}"
\t\t\t\t\t(reference "{ref}")
\t\t\t\t\t(unit 1)
\t\t\t\t)
\t\t\t)
\t\t)
\t)
'''


def emit_wire(x1, y1, x2, y2):
    return (
        f'\t(wire (pts (xy {x1} {y1}) (xy {x2} {y2})) '
        f'(stroke (width 0) (type default)) (uuid "{U()}"))\n'
    )


def emit_label(text, x, y, rot=0):
    return (
        f'\t(label "{text}" (at {x} {y} {rot}) '
        f'(effects (font (size 1.27 1.27)) (justify left bottom)) '
        f'(uuid "{U()}"))\n'
    )


def emit_global_label(text, x, y, rot=0, shape="bidirectional"):
    return (
        f'\t(global_label "{text}" (shape {shape}) (at {x} {y} {rot}) '
        f'(effects (font (size 1.27 1.27)) (justify left)) '
        f'(uuid "{U()}"))\n'
    )
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

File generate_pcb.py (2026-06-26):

"""
generate_pcb.py
---------------
Populates `smart_home.kicad_pcb` with all 42 footprints from the BOM and the
implied netlist for the Smart Home 4-channel AC relay controller.

The existing PCB file is read and used as the base; only the (net 0 "") line
is replaced with the full net table, and footprint blocks are inserted just
before the final closing paren. All existing board outline / mounting hole /
silkscreen content is preserved verbatim.

Inputs:
  - smart_home.kicad_pcb   (current PCB, with only board outline + holes + silk)
  - bom.csv                (component list)
  - hlk_pm01.pretty/HLK-PM01.kicad_mod        (local custom footprint)
  - C:/Program Files/KiCad/9.0/share/kicad/footprints/*.pretty/*.kicad_mod

Outputs:
  - smart_home.kicad_pcb   (rewritten with footprints + nets)
"""

from __future__ import annotations

import os
import re
import uuid
from pathlib import Path

# ---------------------------------------------------------------------------
# Paths
# ---------------------------------------------------------------------------
HERE = Path(__file__).resolve().parent
PCB_PATH = HERE / "smart_home.kicad_pcb"
KICAD_FP_ROOT = Path(r"C:\Program Files\KiCad\9.0\share\kicad\footprints")
LOCAL_FP_LIBS = {"hlk_pm01": HERE / "hlk_pm01.pretty"}


# ---------------------------------------------------------------------------
# Board geometry (kept in sync with the static PCB header section).
# Board outline: 200 x 100 mm.
# Isolation slot: x in [110, 118], y in [5, 95] (8mm wide, full board height
# minus corner-hole keepout).
# HV side: x in [0, 110); HV component bodies must satisfy x_max <= 106
# (4mm DRC clearance from slot edge at x=110).
# LV side: x in (118, 200]; LV component bodies must satisfy x_min >= 122
# (4mm clearance from slot edge at x=118).
# Mounting holes: (5,5), (195,5), (5,95), (195,95), radius 1.6mm — keep
# all bodies ≥0.6mm from hole edge (footprint courtyards typically include
# pad annular ring).
# ---------------------------------------------------------------------------
BOARD_W = 200.0
BOARD_H = 100.0
SLOT_X_MIN, SLOT_X_MAX = 110.0, 118.0
HV_X_LIMIT = 106.0
LV_X_LIMIT = 122.0

# ---------------------------------------------------------------------------
# Component table
# Each entry: ref, value, lib_id, position (x, y, rotation)
# ---------------------------------------------------------------------------

# Footprint lib_ids — some BOM strings are slightly off (commas, missing files);
# normalize here to actual KiCad 9 library footprints.
FP_FUSE_HOLDER = "Fuse:Fuseholder_Cylinder-5x20mm_Schurter_0031_8201_Horizontal_Open"
FP_VARISTOR = "Varistor:RV_Disc_D9mm_W5.2mm_P5mm"
FP_INPUT_TB = "TerminalBlock_Phoenix:TerminalBlock_Phoenix_MKDS-1,5-3-5.08_1x03_P5.08mm_Horizontal"
FP_OUTPUT_TB = "TerminalBlock_Phoenix:TerminalBlock_Phoenix_MKDS-1,5-2-5.08_1x02_P5.08mm_Horizontal"
FP_RELAY = "Relay_THT:Relay_SPDT_SANYOU_SRD_Series_Form_C"

# Layout notes (all sizes are full courtyard extents; origin = pad-1 typically):
#   - Relay SANYOU SRD courtyard: 20mm (x) x 16mm (y), pad1 at (0,0); rot=0 -> spans (-1.55..18.55, -7.95..7.95)
#   - HLK-PM01 courtyard: ~35mm (x) x ~22mm (y), pad1 at (0,0); spans (-3.85..31.35, -5.6..15.8)
#   - ESP32-WROOM-32 module: ~28mm (x) x ~18mm (y), centered around (0,0); spans roughly (-9..+9, -14..+14)
#   - DIP-16 W7.62mm: ~10mm x 21mm, pad1 at (0,0); spans (-2..+9.62, -1.8..+19.8)
#   - SW_PUSH_6mm courtyard: ~7mm x 7mm centered; pads 1 at (-3.25,-2.5) and (-3.25, 2.5); pads 2 at (3.25,-2.5),(3.25,2.5)
#   - LED_D3.0mm: ~4mm dia + 2.54 pad spacing; pad1 at (-1.27,0)
#   - 0805 SMD: ~2mm courtyard
#   - CP_Radial_D6.3mm_P2.50mm: ~7mm dia
#   - Fuseholder 5x20mm Schurter Horizontal Open: ~27mm x 9mm; pads at (0,0) and (22.5,0)
#   - Varistor RV_Disc_D9mm_W5.2mm_P5mm: ~9mm dia, pads at (0,0) and (5,0)
#   - Phoenix MKDS-1.5-3 P5.08 Horizontal: ~15.2mm x 8.2mm; pad1 at (0,0)
#   - Phoenix MKDS-1.5-5: ~25.4mm x 8.2mm
#   - PinHeader 1x06 P2.54: ~3mm x 15mm; pad1 at (0,0)

COMPONENTS = [
    # =====================================================================
    # HV side: 200x100 mm board, isolation slot at x=110..118.
    # HV area: x in [0..110); component bodies must end at x_max <= 106
    # (4mm DRC clearance from slot edge). Mounting holes at the four
    # corners: (5,5), (195,5), (5,95), (195,95), radius 1.6mm — clear
    # disc radius extends to 6.6 from each corner-hole center.
    # ---------------------------------------------------------------------
    # 4 fully-isolated AC channels — each channel is one horizontal row:
    #   J1x (3-pos in) -> Fx (fuse) -> Kx.COM (relay) -> J2x (2-pos out)
    #   J1x pin 2=Nx is bonded inside the terminal block; passes through to
    #   J2x pin 2 as the channel-N return.
    #   J1x pin 3=PE bonds to a shared PE chassis bus net.
    # PS1 + RV1 are auxiliary HV components powered from L1/N1 (channel 1).
    # PS1 sits above the four channel rows in the AC-supply strip.
    # =====================================================================
    # Row centers (y): 30, 50, 70, 90. Spacing 20mm. Each row consumes
    # ~16mm vertically (relay body is 16mm tall). PS1 + RV1 above (y<22).
    # =====================================================================

    # ---- HV auxiliary components ("AC supply" strip, y<22) ----
    # PS1: HLK-PM01 powered from L1 (pad1) and N1 (pad2). +5V on pad3, GND pad4.
    # Footprint pad1 at (0,0); courtyard (-3.85,-5.6)..(31.35,15.8).
    # Pad1=(12,6) avoids (5,5) mounting-hole annulus (1.6mm radius);
    # courtyard x=8.15..43.35, y=0.40..21.80. Pad1 at (12,6) -> distance
    # to hole center (5,5) = sqrt(49+1)=7.07mm, clears.
    # y_max=21.80 < 22.05 = row1 K1 y_min — courtyards just clear.
    dict(ref="PS1", value="HLK-PM01",    fp_id="hlk_pm01:HLK-PM01",                                   x=12.0, y=6.0,  rot=0),

    # RV1: varistor S07K275, 9mm dia, 5mm pin pitch. Across L1/N1 (post-fuse).
    # Pads at (cx, cy), (cx+5, cy). Courtyard (-2.25, -1.6)..(7.25, 4.1) rel to pad1.
    # Pad1=(52,8): courtyard x=49.75..59.25, y=6.4..12.1. To right of PS1
    # (PS1 courtyard x_max=43.35, gap 6.4mm). Above all channel rows
    # (row 1 at y=30, K1 body y_min=22.05).
    dict(ref="RV1", value="S07K275",     fp_id=FP_VARISTOR,                                           x=52.0, y=8.0,  rot=0),
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

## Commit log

2026-05-26 Initial commit: KiCad project for 4-channel ESP32 smart home AC relay PCB
    ESP32-WROOM-32E + HLK-PM01 (230VAC->5V) + 4x SRD-05VDC relays, with
    ULN2003 driver, manual override buttons, UART programming header.
    Includes custom HLK-PM01 symbol/footprint, HV/LV separation DRC rules,
    100x80mm board outline with isolation slot, and full BOM.
    [bom.csv, smart_home.kicad_pcb, smart_home.kicad_sch]
2026-06-26 Complete 4-channel smart home AC relay PCB design
    Full KiCad 9 design for a 230V AC 4-channel smart home relay controller:
    - ESP32-WROOM-32E + ULN2003A + 4x SANYOU SRD relays
    - 4 isolated AC inputs (own L/N/PE + fuse per channel)
    - 4 AC outputs (L_switched + N_passthrough per channel)
    - HLK-PM01 isolated AC-DC + AMS1117-3.3 LDO for logic
    - Per-channel current sense (4x ACS712-05B + ADC dividers)
    - Per-channel voltage sense (ADS1115 I2C ADC + external ZMPT101B headers)
    - 4-pin I2C header for 16x2 LCD module (PCF8574 backpack)
    - Manual override buttons + status LEDs per channel
    - 6-pin UART programming header
    - Custom DRC: 4mm HV-LV clearance, 3mm HV-HV, 2mm HV trace minimum
    - Physical HV/LV i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
    [bom.csv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]
2026-06-26 Add full component details to README and company name to PCB
    - Update company in title block: Wisright -> WisRight Technologies Private Limited
    (smart_home.kicad_sch, smart_home.kicad_pcb, generate_sch.py)
    - Add silkscreen on PCB:
    * Front silk (bottom center): "WisRight Technologies Private Limited" (bold 1.4mm)
    * Back silk (top, mirrored): "Smart Home 4-Channel AC Relay Controller - Rev 0.1"
    * Back silk (bottom, mirrored): "(c) 2026 WisRight Technologies Pvt Ltd"
    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
    [smart_home-B_Adhesive.gbr, smart_home-B_Courtyard.gbr, smart_home-B_Cu.gbr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]
2026-06-26 Add 3D model for HLK-PM01 (was missing in 3D viewer)
    Create hlk_pm01.pretty/HLK-PM01.wrl — VRML 2.0 model representing
    the 34.2 x 20.2 x 15 mm black plastic enclosure with a lighter top label area.
    Reference the model from both the library footprint (HLK-PM01.kicad_mod)
    and the PCB's embedded instance (smart_home.kicad_pcb PS1 footprint).
    The 3D viewer in KiCad PCB editor now shows the HLK-PM01 module body
    sitting on the board instead of just the silkscreen outline.
    Note: WRL is shown in the interactive 3D viewer; for STEP export to also
    include this body, a separate .step model file would be needed.
    [smart_home.kicad_pcb]
2026-06-26 Include HLK-PM01.wrl in repo (gitignore fix)
    The previous commit added hlk_pm01.pretty/HLK-PM01.wrl on disk but the
    *.wrl gitignore pattern silently dropped it from version control.
    Restrict the WRL ignore so .wrl files inside *.pretty/ footprint
    directories are tracked (they are part of the design, not output).
2026-06-26 Fix HLK-PM01 3D model scale (was rendered ~3x oversize)
    KiCad VRML legacy convention treats 1 WRL unit = 0.1 inch = 2.54 mm.
    Since the model is authored in mm, set scale to 1/2.54 = 0.3937 in both
    the library footprint and the PCB instance so the body renders at its
    real 34.2 x 20.2 x 15 mm dimensions.
    [smart_home.kicad_pcb]
2026-06-26 Expand BOM with manufacturer parts, sourcing notes, external modules
    bom.csv:
    - Add manufacturer names (Espressif, TI, Allegro, Phoenix Contact, etc.)
    - Add specific MPNs for sourcing (Yageo / Samsung MLCC / Schurter fuse holder)
    - Properly quote J1A-J1D and J2A-J2D footprint fields (the unquoted commas
    in MKDS-1,5 part names were a CSV parsing hazard)
    - More descriptive Notes per part (placement guidance, alternatives, ratings)
    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
    [bom.csv, smart_home.kicad_sch]
2026-06-26 Run Freerouting autoroute on updated PCB (post ACS712+ADS1115)
    Process:
    1. Pcbnew Python API: rip up all 426 stale tracks/42 vias from prior pass
    (they predated the ACS712 net-topology change and were inconsistent)
    2. Export fresh Specctra DSN (smart_home.dsn)
    3. Freerouting 1.9.0 batch autoroute, 50 passes, 4 threads
    4. Import SES back via pcbnew.ImportSpecctraSES
    Result: 368 segments + 28 vias placed across 32 nets.
    DRC: 59 violations (36 clearance — Freerouting doesn't honor the custom
    .kicad_dru HV clearance rule, so HV nets need a manual cleanup pass in
    the PCB editor), plus 19 cosmetic (silk overlap, lib_footprint_mismatch).
    Unconnected: 66 ratsnest items remain — mostly HV cha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
    [smart_home-B_Adhesive.gbr, smart_home-B_Courtyard.gbr, smart_home-B_Cu.gbr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]
